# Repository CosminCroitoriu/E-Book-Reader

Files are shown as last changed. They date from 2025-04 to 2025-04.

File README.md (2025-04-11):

Nume: Croitoriu Cosmin-Mircea  
Grupă: 332CB

# TSC Project - OpenBook E-Book Reader
Overview
-
This diagram illustrates the hardware architecture of the OpenBook E-Reader, an ESP32-based electronic paper reading device. The system is built around the ESP32-C6-WROOM-1 microcontroller, which interfaces with a 7.5-inch e-Paper display, environmental sensors, and user input buttons.  

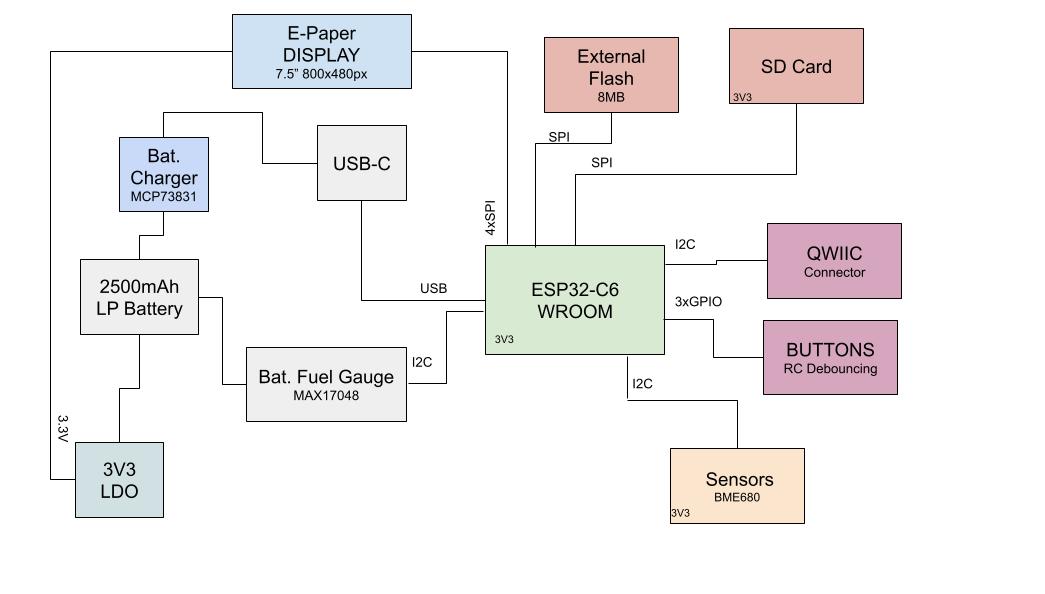
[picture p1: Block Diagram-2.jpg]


***Key Components:*** 

* Core Processing: ESP32-C6 microcontroller with integrated Wi-Fi 6 and BLE 5
* Display: 800×480 resolution e-Paper display connected via SPI
* Sensors: BME688 for temperature, humidity, pressure, and air quality monitoring via I2C
* Power: 2500mAh LiPo battery with fuel gauge and USB-C charging
* Storage: SD card interface for e-book storage via SPI
* Timekeeping: DS3231 RTC with backup power
* User Interface: Buttons via 3xGPIO
* Expansion: QWIIC/Stemma connector for additional peripherals

The firmware is built on FreeRTOS and includes specialized modules for display management, sensor monitoring, battery management, user interface, and e-book rendering. This modular architecture ensures flexible development, easy maintenance, and power-efficient operation—essential for an e-reader device with long battery life requirements.

Power Consumption
-

* In active reading mode (display updated occasionally): ~15-30mA
* In display update mode: ~50-100mA temporarily
* In Wi-Fi active mode: ~120-180mA
* In sleep mode: ~1-5mA
* In deep sleep mode: <50µA

With a 2500mAh battery, the device can operate approximately:

* 100-150 hours in active reading mode (without Wi-Fi)
* 15-20 hours with Wi-Fi constantly active
* Up to 1500 hours (2 months) in deep sleep mode

ESP32-C6 Pin Assignments
-
| Connection Name | GPIO / Pin Name  | Function  |
|---|---|---|
| **3V3** | IO 8 | 3.3V Power line |
| **EN (Reset)**  | EN | Reset Button | 
| **USB_D-** | IO12 | USB Data negative, communication  | 
| **USB_D+** | IO13 | USB Data positive, communication  |
| **Buton Boot**  | IO9 | Bootbutton  | 
| **Buton Change**| IO15 | User input for state changing  |
| **TX (UART)** | TXD0 / GPIO16 | Serial Transmitter (UART) for communication  |
| **RX (UART)** | RXD0 / GPIO17 | Serial Receiver (UART) for communication  |
| **SCK (SPI)** | IO6 | SPI Clock for clock synchronization |
| **MOSI (SPI)**  | IO7 | Transmitter between MC and the Flash, SD Card and display |
| **MISO (SPI)**  | IO2 | Receiver between MC and the Flash, SD Card and display |
| **FLASH_CS** | IO11 | Flash Chip Select |
| **EPD_CS** | IO10 | Display Chip select |
| **EPD_DC** | IO5 | Display Command |
| **EPD_RST** | IO23 | Display Reset |
| **EPD_BUSY** | IO3 | Busy Display Signal |
| **SDA (I2C)** | IO21 | Bidirectional Communication RTC, BME688, Battery Gauge |
| **SCL (I2C)** | IO22 | I2C synchronization |
| **SS_SD** | IO4 | SD Card Chip Select |
| **I2C_PW** | IO19 | Power Control on I2C |
| **EPD_3V3_C** | IO20 | 3.3V Power Line for the Display |
| **32KHZ** | IO1 | 32kHz Signal Input |
| **INT_RTC** | IO0 | RTC DS3231 Interrupt |
| **RTC_RST** | IO18 | External Reset RTC | 

Bill of Materials
-

| Component | Value | Assigned Part | Where to buy | Datasheet |
| --- | --- | --- | --- | ----- |
| Resistor | 15	$\Omega$ | R_CAPACITOR | [Buy](https://ro.mouser.com/ProductDetail/YAGEO/RT0402FRE0715RL?qs=BXCcY9r%252B08DFFpLSkPOIqQ%3D%3D) | [Datasheet](https://ro.mouser.com/datasheet/2/447/PYu_RT_1_to_0_01_RoHS_L_15-3461507.pdf) |
| Resistor | 200 $\Omega$ | R1_BAT | [Buy](https://ro.mouser.com/ProductDetail/Vishay-Beyschlag/MCS0402MD2000BE100?qs=3SvaY9RawMJNVte4F12%252BZQ%3D%3D) | [Datasheet](https://www.vishay.com/doc?28952) |
| Resistor | 100k $\Omega$ | R_PWRUSB | [Buy](https://ro.mouser.com/ProductDetail/Vishay-Beyschlag/MCT0603PD1003DP500?qs=5aG0NVq1C4wWAn8Ei3OpZA%3D%3D) | [Datasheet](https://www.vishay.com/doc?28916) |
| Resistor | 10k $\Omega$ | R1, R1_PINH1, R1_PINH2, R2-PINH1, R2_PINH2, R4, R5, R6, R7, R8, R9, R10, R_BOOT, R_CHANGE, R_CL1, R_RESET | [Buy](https://ro.mouser.com/ProductDetail/Vishay-Beyschlag/MCS0402MD1002BE000?qs=17u8i%2FzlE8%2F9BrAaXkMk1w%3D%3D) | [Datasheet](https://www.vishay.com/doc?28952) |
| Resistor | 0.47 $\Omega$ | R3 | [Buy](https://ro.mouser.com/ProductDetail/SEI-Stackpole/CSR0402JKR470?qs=IPgv5n7u5QawIB6nBEt8wA%3D%3D) | [Datasheet](https://ro.mouser.com/datasheet/2/385/SEI_CSR_CSRN-3077593.pdf) |
| Resistor |  2k $\Omega$ | R2_BAT |[Buy](https://ro.mouser.com/ProductDetail/Vishay-Beyschlag/MCS04020C2001FE000?qs=wTZ%2FFzl837YG0wIkZJJOwQ%3D%3D) | [Datasheet](https://www.vishay.com/doc?28705) |
| Resistor | 2.2 $\Omega$ | R2 | [Buy](https://ro.mouser.com/ProductDetail/SEI-Stackpole/RMCF0402FT2R20?qs=IPgv5n7u5QbBgyl0jwhwsA%3D%3D) | [Datasheet](https://ro.mouser.com/datasheet/2/385/SEI_RMCF_RMCP-3077565.pdf) |
| Resistor | 5k1 $\Omega$ | R1_USB, R2_USB | [Buy](https://www.venkel.com/part/TFCR0603-16W-K-5690FT) | [Datasheet](https://data.venkel.com/documents/tfcr-series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.) |
| Capacitor | 10uF | C6 | [Buy](https://ro.mouser.com/ProductDetail/Samsung-Electro-Mechanics/CL10A106KQ8NNNL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) | [Datasheet](https://ro.mouser.com/datasheet/2/585/MLCC-1837944.pdf) |
| Capacitor | 1uF/50V | EPD_C3 | [Buy](https://ro.mouser.com/ProductDetail/KYOCERA-AVX/06035D105MAT2A?qs=k4kUdCzLgS5%252BURKe1SOIeQ%3D%3D) | [Datasheet](https://ro.mouser.com/datasheet/2/40/cx5r_KGM-3223198.pdf) |
| Capacitor | 4.7uF | C1_BAT, C1_BAT1, C2_BAT, C2_BAT1, C4_USB | [Buy](https://ro.mouser.com/ProductDetail/KYOCERA-AVX/0402ZD475MAT2A?qs=NBFAU1oqP4W4U2PCPHI0sg%3D%3D) | [Datasheet](https://ro.mouser.com/datasheet/2/40/cx5r_KGM-3223198.pdf) |
| Capacitor | 100nF | C1, C2, C3_USB, C5, C7, C8, C9, C_DELAY | [Buy](https://ro.mouser.com/ProductDetail/KYOCERA-AVX/06033G104ZAT2A?qs=NXubJDmysXJMPmHfVo6Z%252BA%3D%3D) | [Datasheet](https://ro.mouser.com/datasheet/2/40/KGM_Y5V-3223189.pdf) |
| PFMF.050.1 | - | PFMF.050.1 | [Buy](https://ro.mouser.com/ProductDetail/Schurter/PFMF.050.2?qs=1auRipcfynCums5v1iucSA%3D%3D) |  [Datasheet](https://ro.mouser.com/datasheet/2/358/typ_PFMF-1275918.pdf) |
| USB4110-GF-A | - | J2 | [Buy](https://ro.mouser.com/ProductDetail/GCT/USB4110-GF-A?qs=KUoIvG%2F9IlYiZvIXQjyJeA%3D%3D) | [Datasheet](https://ro.mouser.com/datasheet/2/837/GCT_USB4110_Product_Drawing___20k_cycles-3455479.pdf) |
| USBLC6-2SC6Y | - | D1 | [Buy](https://ro.mouser.com/ProductDetail/STMicroelectronics/USBLC6-2SC6Y?qs=gNDSiZmRJS%2FOgDexvXkdow%3D%3D) | [Datasheet](https://ro.mouser.com/datasheet/2/389/usblc6_2sc6y-1852505.pdf) |
| SD0805S020S1R0 | - | D2, D7| [Buy](https://ro.mouser.com/ProductDetail/KYOCERA-AVX/SD0805S020S1R0?qs=jCA%252BPfw4LHbpkAoSnwrdjw%3D%3D) | [Datasheet](https://ro.mouser.com/datasheet/2/40/schottky-3165252.pdf) |
| DMG2305UX-7 | - | Q1, Q2 | [Buy](https://ro.mouser.com/ProductDetail/Diodes-Incorporated/DMG2305UX-7?qs=L1DZKBg7t5F%2FNBHrjfxC%252Bg%3D%3D) | [Datasheet](https://www.diodes.com/assets/Datasheets/DMG2305UX.pdf) |
| XC6220A331MR-G | - | U5 | [Buy](https://ro.mouser.com/ProductDetail/Torex-Semiconductor/XC6220A331MR-G?qs=AsjdqWjXhJ8ZSWznL1J0gg%3D%3D) | [Datasheet](https://ro.mouser.com/datasheet/2/760/xc6220-3371556.pdf) |
| Capacitor | 100 uF TANT | C_TANT | [Buy](https://ro.mouser.com/ProductDetail/KYOCERA-AVX/TAJW107M010RNJ?qs=Wtp%252Bf%2FAeVqIH8v1VxV%252B1Rg%3D%3D) | [Datasheet](https://ro.mouser.com/datasheet/2/40/TAJ-3165264.pdf) |
| 112A-TAAR-R03_ATTEND | - | J4 | [Buy](https://www.digikey.ro/en/products/detail/attend-technology/112A-TAAR-R03/17633923) | [Datasheet](https://www.attend.com.tw/data/download/file/112A-TAAR-R03_Spec.pdf)
| ESP32-C6-WROOM-1-N8 | - | U1 | [Buy](https://ro.mouser.com/ProductDetail/Espressif-Systems/ESP32-C6-WROOM-1-N8?qs=8Wlm6%252BaMh8ST02Gmwp74cw%3D%3D) | [Datasheet](https://ro.mouser.com/datasheet/2/891/Espressif_ESP32_C6_WROOM_1__Datasheet_V0_1_PRELIMI-3239987.pdf) |
| MCP73831 | - | U7 | [Buy](https://ro.mouser.com/ProductDetail/Microchip-Technology/MCP73831T-2ACI-OT?qs=yUQqVecv4qvbBQBGbHx0Mw%3D%3D) | [Datasheet](https://ro.mouser.com/datasheet/2/268/MCP73831_Family_Data_Sheet_DS20001984H-3441711.pdf) |
| CHG_LED | - | CHG_LED | [Buy](https://store.comet.srl.ro/Catalogue/Product/40478/) | [Datasheet](https://www.snapeda.com/parts/KP-1608SURCK/Kingbright/datasheet/) |
| SI1308EDL-T1-GE3 | - | Q3 | [Buy](https://ro.mouser.com/ProductDetail/Vishay-Semiconductors/SI1308EDL-T1-GE3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) | [Datasheet](https://www.vishay.com/doc?63399) |
| MBR0530 | - | D3, D4, D5 | [Buy](https://ro.mouser.com/ProductDetail/Micro-Commercial-Components-MCC/MBR0530-T?qs=9VyI4qLX4NTSXkb9ynzJnA%3D%3D) | [Datasheet](https://ro.mouser.com/datasheet/2/258/mcc_mbr0520~mbr0560sod123-1179695.pdf) |
| Power Inductor | 68uH | L1 | [Buy](https://ro.mouser.com/ProductDetail/Wurth-Elektronik/744043680?qs=PGXP4M47uW6VkZq%252BkzjrHA%3D%3D) | [Datasheet](https://www.we-online.com/components/products/datasheet/744043680.pdf) |
| FH34SRJ-24S-0.5SH | - | J1 | [Buy](https://ro.mouser.com/ProductDetail/Hirose-Connector/FH34SRJ-24S-0.5SH99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) | [Datasheet](https://ro.mouser.com/datasheet/2/185/FH34SRJ_24S_0_5SH_99__CL0580_1255_6_99_2DDrawing_0-1615044.pdf) |
| BME688 Sensor | - | U8 | [Buy](https://ro.mouser.com/ProductDetail/Bosch-Sensortec/BME688?qs=IS%252B4QmGtzzqQoVDscqwx3A%3D%3D) | [Datasheet](https://ro.mouser.com/datasheet/2/783/bst_bme688_fl000-2307034.pdf) |
| BD5229G-TR | - | U6 |[Buy](https://ro.mouser.com/ProductDetail/ROHM-Semiconductor/BD5229G-TR?qs=4kLU8WoGk0vvnhrrYwdszw%3D%3D) | [Datasheet](https://fscdn.rohm.com/en/products/databook/datasheet/ic/power/voltage_detector/bd52xxg-e.pdf) |
| PTS841 Button | - | BOOT_BUTTON, CHANGE_BUTTON, RESET_BUTTON | [Buy](https://ro.mouser.com/ProductDetail/CK/PTS841-ESD-GKP-SMTR-LFS?qs=d0WKAl%252BL4KbeUlwuiSQZWA%3D%3D) | [Datasheet](https://www.ckswitches.com/media/2805/pts841.pdf) |
| MAX17048G+T10 | - | U2 | [Buy](https://ro.mouser.com/ProductDetail/Analog-Devices-Maxim-Integrated/MAX17048G%2bT10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) | [Datasheet](https://ro.mouser.com/datasheet/2/609/MAX17048_MAX17049-3469099.pdf) |
| W25Q512JVEIQ | - | U4 | [Buy](https://ro.mouser.com/ProductDetail/Winbond/W25Q512JVEIQ?qs=l7cgNqFNU1jw6svr3at6tA%3D%3D) | [Datasheet](https://ro.mouser.com/datasheet/2/949/Winbond_W25Q512JV_Datasheet-3240039.pdf) |
| PGB1010603MR | - | D6, D8, D9, D10, D11, D12 | [Buy](https://ro.mouser.com/ProductDetail/Littelfuse/PGB1010603MRHF?qs=KvZd0dN2Zg%2FuIq6icj%252BGKA%3D%3D) | [Datasheet](https://www.littelfuse.com/media?itemid=8a337998-d54d-466b-be4e-dc5bcd1f9321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) |
| QWIIC_RIGHT_ANGLE | - | J3 | [Buy](https://ro.mouser.com/ProductDetail/GCT/USB4110-GF-A?qs=KUoIvG%2F9IlYiZvIXQjyJeA%3D%3D) | [Datasheet](https://ro.mouser.com/datasheet/2/837/GCT_USB4110_Product_Drawing___20k_cycles-3455479.pdf) |
| DS3231SN | - | U3 | [Buy](https://ro.mouser.com/ProductDetail/Analog-Devices-Maxim-Integrated/DS3231SN?qs=ffX8NcjNb2RmKAb9wAk9Ug%3D%3D) | [Datasheet](https://ro.mouser.com/datasheet/2/609/DS3231-3421123.pdf) |
| CPH3225A | - | C_SUPERCAP | [Buy](https://ro.mouser.com/ProductDetail/Seiko-Semiconductors/CPH3225A?qs=3etwrb1wR%252BhUOph6lAO7eg%3D%3D) | [Datasheet](https://ro.mouser.com/datasheet/2/360/Seiko_Instruments_MicroBattery_E_20230330_2024Jan_-3561061.pdf) |

Design Considerations
-

* The modular design allows for individual component updates and easy problem diagnosis
* Using a single LDO regulator to generate 3.3V for the entire board simplifies the power design
* Battery charging is done through the USB-C port, ensuring wide compatibility
* The environmental sensors allow for monitoring the conditions in which the device is used and can be used to alert the user about unfavorable conditions
* Used a predefined 3D model for the screen. Source: https://grabcad.com/library/7-5in-e-ink-display-assortment-1

PCB Observations
-

* PCB Dieletctric layer has been reduced from 1.6mm to 1mm to fit in the case.
* Via Stitching has been applied around the MC, so the impedance of the ground plane is lowered.

Errors and Warnings
- 
* The Board Outline Clearence errors were all approved, as every component was matching the placement in the given document.
* Unconnected Lines warnings are a bug from Fusion, as everytime I try to remove them, the error reappears. 
* Copper Width errors for the inductor were approved as the model matched the one in the givne scheme.

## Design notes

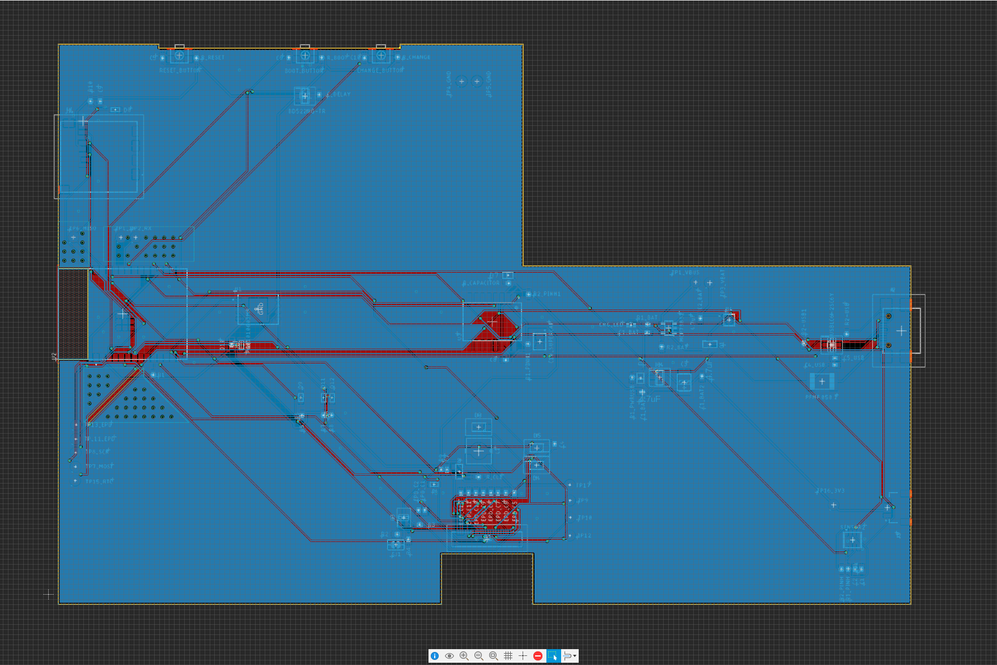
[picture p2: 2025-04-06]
Images/PCB BOTTOM.png

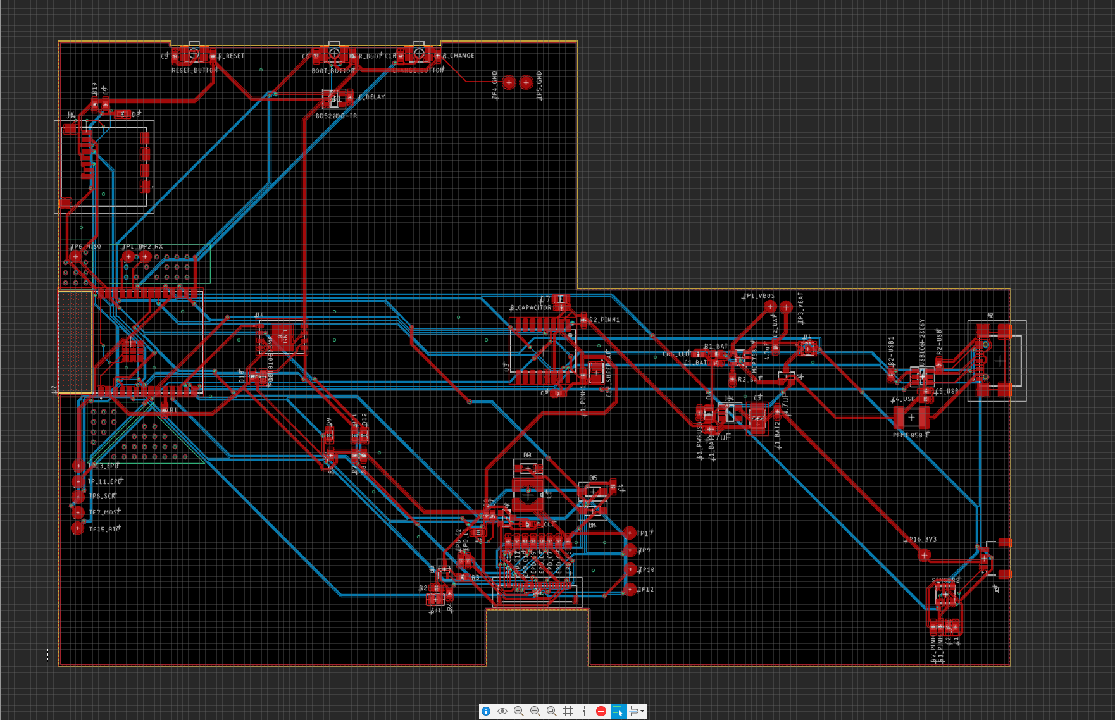
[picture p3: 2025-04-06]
Images/PCB COMPS.png

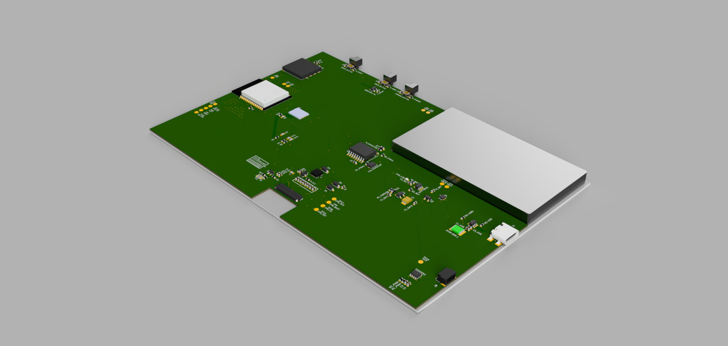
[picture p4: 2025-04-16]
Images/OpenBook_Enclosure Case Fit.jpg

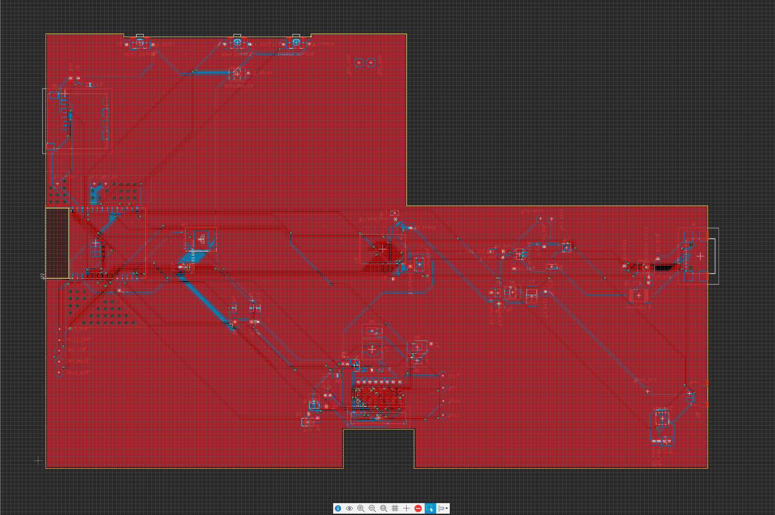
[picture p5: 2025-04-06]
Images/PCB TOP.png

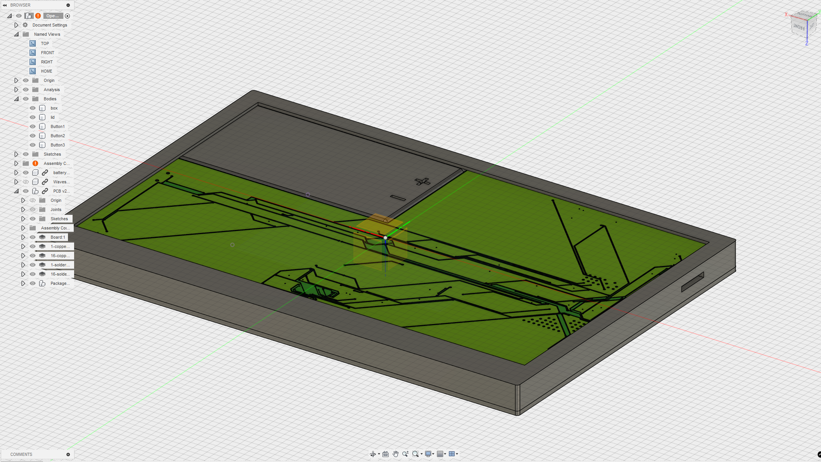
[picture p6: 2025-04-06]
Images/PCB and BATTERY FIT.png

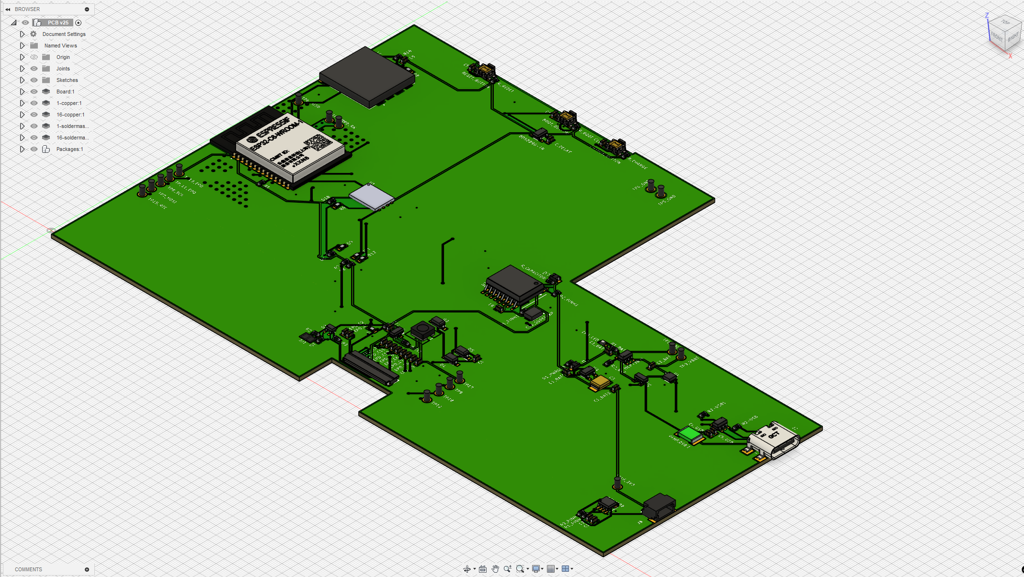
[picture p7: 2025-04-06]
Images/3D PCB.png

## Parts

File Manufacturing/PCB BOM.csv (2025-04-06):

Qty | Value | Device | Package | Parts | Description | ARROW_PART_NUMBER | ARROW_PRICE-STOCK | AVAILABILITY | CENTROID_NOT_SPECIFIED | CHECK_PRICES | COPYRIGHT | DATASHEET | DESCRIPTION | DIGIKEY_DESCRIPTION | DIGIKEY_PART_NUMBER | HEIGHT | LEAD_FREE | MANUFACTURER_NAME | MANUFACTURER_PART_NUMBER | MF | MFR_NAME | MOUSER_PART_NUMBER | MOUSER_PRICE-STOCK | MOUSER_TESTING_PART_NUMBER | MOUSER_TESTING_PRICE-STOCK | MP | MPN | PACKAGE | POPULARITY | PREFIX | PRICE | PROD_ID | PURCHASE-URL | ROHS | SNAPEDA_LINK | SPICEMODEL | SPICEPREFIX | TEMPERATURE_RANGE_HIGH | TEMPERATURE_RANGE_LOW | TP_SIGNAL_NAME | VALUE
1 |  | ADAFRUIT_LEDCHIP-LED0603 | ADAFRUIT_CHIP-LED0603 | CHG_LED | LED
1 |  | SJ | SJ | SJ1 | SMD solder JUMPER |  |  |  |  |  |  |  |  |  |  |  |  |  |  |  |  |  |  |  |  |  |  |  | 3
1 | 0.47 | ESP32_WROVER_EAGLE-LTSPICE_RR0402 | ESP32_WROVER_EAGLE-LTSPICE_R0402 | R3 | RESISTOR, European symbol |  |  |  |  |  |  |  |  |  |  |  |  |  |  |  |  |  |  |  |  |  |  |  |  |  |  |  |  |  |  | NONE | R
1 | 01.uF/50V | EAGLE-LTSPICE_CC0402 | EAGLE-LTSPICE_C0402 | EPD_C5 | CAPACITOR, European symbol |  |  |  |  |  |  |  |  |  |  |  |  |  |  |  |  |  |  |  |  |  |  |  |  |  |  |  |  |  |  | NONE | C
1 | 100K | ESP32_WROVER_EAGLE-LTSPICE_RR0402 | ESP32_WROVER_EAGLE-LTSPICE_R0402 | R1_PWRUSB | RESISTOR, European symbol |  |  |  |  |  |  |  |  |  |  |  |  |  |  |  |  |  |  |  |  |  |  |  |  |  |  |  |  |  |  | NONE | R
8 | 100nF | EAGLE-LTSPICE_CC0402 | EAGLE-LTSPICE_C0402 | C1, C2, C4_USB, C6, C8, C9, C10, C_DELAY | CAPACITOR, European symbol |  |  |  |  |  |  |  |  |  |  |  |  |  |  |  |  |  |  |  |  |  |  |  |  |  |  |  |  |  |  | NONE | C
1 | 100uF TANT | RCL_CPOL-EUCT3528 | RCL_CT3528 | C3 | POLARIZED CAPACITOR, European symbol |  |  |  |  |  |  |  |  |  |  |  |  |  |  |  |  |  |  |  |  |  |  |  | 0 |  |  |  |  |  |  |  | C
11 | 10K | ESP32_WROVER_EAGLE-LTSPICE_RR0402 | ESP32_WROVER_EAGLE-LTSPICE_R0402 | R1_PINH1, R2_PINH1, R5, R6, R7, R8, R9, R10, R_BOOT, R_CHANGE, R_RESET | RESISTOR, European symbol |  |  |  |  |  |  |  |  |  |  |  |  |  |  |  |  |  |  |  |  |  |  |  |  |  |  |  |  |  |  | NONE | R
5 | 10k | ESP32_WROVER_EAGLE-LTSPICE_RR0402 | ESP32_WROVER_EAGLE-LTSPICE_R0402 | R1, R1_PINH, R2_PINH, R4, R_CL1 | RESISTOR, European symbol |  |  |  |  |  |  |  |  |  |  |  |  |  |  |  |  |  |  |  |  |  |  |  |  |  |  |  |  |  |  | NONE | R
1 | 10uF | EAGLE-LTSPICE_CC0402 | EAGLE-LTSPICE_C0402 | C7 | CAPACITOR, European symbol |  |  |  |  |  |  |  |  |  |  |  |  |  |  |  |  |  |  |  |  |  |  |  |  |  |  |  |  |  |  | NONE | C
1 | 112A-TAAR-R03_ATTEND | 112A-TAAR-R03_ATTEND | 112ATAARR03ATTEND | J4 | Micro SD Card Socket, Push-Push Type, Top Mount, SMT, H=1.83mm, 10u |  |  |  |  |  |  |  | Micro SD Card Socket | Push-Push Type | Top Mount | SMT | H=1.83mm | 10u |  |  | 1.9mm |  | ATTEND | 112A-TAAR-R03 ATTEND
1 | 15 | ESP32_WROVER_EAGLE-LTSPICE_RR0402 | ESP32_WROVER_EAGLE-LTSPICE_R0402 | R_CAPACITOR | RESISTOR, European symbol |  |  |  |  |  |  |  |  |  |  |  |  |  |  |  |  |  |  |  |  |  |  |  |  |  |  |  |  |  |  | NONE | R
1 | 1uF | EAGLE-LTSPICE_CC0402 | EAGLE-LTSPICE_C0402 | C5 | CAPACITOR, European symbol |  |  |  |  |  |  |  |  |  |  |  |  |  |  |  |  |  |  |  |  |  |  |  |  |  |  |  |  |  |  | NONE | C
9 | 1uF/50V | EAGLE-LTSPICE_CC0402 | EAGLE-LTSPICE_C0402 | EPD_C1, EPD_C2, EPD_C6, EPD_C7, EPD_C8, EPD_C9, EPD_C10, EPD_C11, EPD_C12 | CAPACITOR, European symbol |  |  |  |  |  |  |  |  |  |  |  |  |  |  |  |  |  |  |  |  |  |  |  |  |  |  |  |  |  |  | NONE | C
1 | 2.2 | ESP32_WROVER_EAGLE-LTSPICE_RR0402 | ESP32_WROVER_EAGLE-LTSPICE_R0402 | R2 | RESISTOR, European symbol |  |  |  |  |  |  |  |  |  |  |  |  |  |  |  |  |  |  |  |  |  |  |  |  |  |  |  |  |  |  | NONE | R
1 | 200 | ESP32_WROVER_EAGLE-LTSPICE_RR0402 | ESP32_WROVER_EAGLE-LTSPICE_R0402 | R1_BAT | RESISTOR, European symbol |  |  |  |  |  |  |  |  |  |  |  |  |  |  |  |  |  |  |  |  |  |  |  |  |  |  |  |  |  |  | NONE | R
2 | 20V/4.2A/52mO/1.4W | ESP32_WROVER_SPARKFUN-DISCRETESEMI_MOSFET_PCH-DMG2305UX-7 | ESP32_WROVER_SPARKFUN-DISCRETESEMI_SOT23-3 | Q1, Q2 | P-channel MOSFETs |  |  |  |  |  |  |  |  |  |  |  |  |  |  |  |  |  |  |  |  |  |  |  |  |  |  | TRAN-14388 |  |  |  |  |  |  |  |  | 20V/4.2A/52mO/1.4W
1 | 2K | ESP32_WROVER_EAGLE-LTSPICE_RR0402 | ESP32_WROVER_EAGLE-LTSPICE_R0402 | R2_BAT | RESISTOR, European symbol |  |  |  |  |  |  |  |  |  |  |  |  |  |  |  |  |  |  |  |  |  |  |  |  |  |  |  |  |  |  | NONE | R
3 | 4.7uF | EAGLE-LTSPICE_CC0402 | EAGLE-LTSPICE_C0402 | C1_BAT, C2_BAT, C5_USB | CAPACITOR, European symbol |  |  |  |  |  |  |  |  |  |  |  |  |  |  |  |  |  |  |  |  |  |  |  |  |  |  |  |  |  |  | NONE | C
2 | 4.7uF | ESP32_WROVER_EAGLE-LTSPICE_CC0402 | EAGLE-LTSPICE_C0402 | C1_BAT1, C1_BAT2 | CAPACITOR, European symbol |  |  |  |  |  |  |  |  |  |  |  |  |  |  |  |  |  |  |  |  |  |  |  |  |  |  |  |  |  |  | NONE | C
1 | 4.7uF/25V | EAGLE-LTSPICE_CC0402 | EAGLE-LTSPICE_C0402 | C4 | CAPACITOR, European symbol |  |  |  |  |  |  |  |  |  |  |  |  |  |  |  |  |  |  |  |  |  |  |  |  |  |  |  |  |  |  | NONE | C
2 | 5k1 | ESP32_WROVER_EAGLE-LTSPICE_RR0402 | ESP32_WROVER_EAGLE-LTSPICE_R0402 | R2-USB, R2-USB1 | RESISTOR, European symbol |  |  |  |  |  |  |  |  |  |  |  |  |  |  |  |  |  |  |  |  |  |  |  |  |  |  |  |  |  |  | NONE | R
1 | 68uH | 744043680IND_4828-WE-TPC_WRE | IND_4828-WE-TPC_WRE | L1 |  |  |  |  |  |  | Copyright (C) 2024 Ultra Librarian. All rights reserved. |  |  |  |  |  |  |  | 744043680 |  | Wurth Electronics
1 | BD5229G-TR | BD5229G-TR | SOT95P280X125-5N | IC1 | Voltage Detector with Adjustable Delay Time: CMOS processes are utilized to develop high precision, low current consumption CMOS reset ICs that allow arbitrary setting of the delay time. The extensive lineup includes both Nch Open Drain and CMOS output types in a wide range of detection voltages (from 2.3V to 6.0V, in 0.1V steps), enabling selection of the ideal solution based on customer requirements. In addition, the entire series is of course both lead-free and RoHS-compliant. |  |  |  |  |  |  |  | Voltage Detector with Adjustable Delay Time: CMOS processes are utilized to develop high precision | low current consumption CMOS reset ICs that allow arbitrary setting of the delay time. The extensive lineup includes both Nch Open Drain and CMOS output types in a wide range of detection voltages (from 2.3V to 6.0V | in 0.1V steps) | enabling selection of the ideal solution based on customer requirements. In addition | the entire series is of course both lead-free and RoHS-compliant. |  |  | 1.25mm |  | ROHM Semiconductor | BD5229G-TR |  |  | 755-BD5229G-TR | https://www.mouser.co.uk/ProductDetail/ROHM-Semiconductor/BD5229G-TR?qs=4kLU8WoGk0vvnhrrYwdszw%3D%3D
3 | BUTTON_CUSYOMV1 | BUTTON_CUSYOMV1 | MYBUTTON | BOOT_BUTTON, CHANGE_BUTTON, RESET_BUTTON
1 | CPH3225A | CPH3225A | CAPCP3225X100N | C10_SUPERCAP | Cap 0.011F 3.3V 1210 Flat Check availability |  |  | Not in stock |  | https://www.snapeda.com/parts/CPH3225A/Seiko+Instruments/view-part/?ref=eda |  |  | 11 mF (EDLC) Supercapacitor 3.3 V 1210 (3225 Metric) - - |  |  |  |  |  |  | Seiko Instruments |  |  |  |  |  | CPH3225A |  | 1210 Seiko |  |  | None |  | https://www.snapeda.com/api/url_track_click_mouser/?unipart_id=562593&manufacturer=Seiko Instruments&part_name=CPH3225A&search_term=None |  | https://www.snapeda.com/parts/CPH3225A/Seiko+Instruments/view-part/?ref=snap
1 | DS3231SN# | DS3231SN# | SOIC127P1032X265-16N | U3 | Real Time Clock Serial 16-Pin SOIC W T/R Check availability |  |  | In Stock |  | https://www.snapeda.com/parts/DS3231SN%23/Analog+Devices/view-part/?ref=eda |  |  | Extremely Accurate I²C-Integrated RTC/TCXO/Crystal |  |  |  |  |  |  | Analog Devices |  |  |  |  |  | DS3231SN# |  | SOIC-16 Maxim |  |  | None |  | https://www.snapeda.com/api/url_track_click_mouser/?unipart_id=99048&manufacturer=Analog Devices&part_name=DS3231SN#&search_term=None |  | https://www.snapeda.com/parts/DS3231SN%23/Analog+Devices/view-part/?ref=snap
1 | ESP32-C6-WROOM-1-N8 | ESP32-C6-WROOM-1-N8 | XCVR_ESP32-C6-WROOM-1-N8 | U2 | Check availability |  |  | In Stock |  | https://www.snapeda.com/parts/ESP32-C6-WROOM-1-N8/Espressif+Systems/view-part/?ref=eda |  |  | Multiprotocol Modules ESP32-C6 module | Wi-Fi 6 in 2.4 GHz band | Bluetooth 5 | Zigbee 3.0 and Thread. ESP34-WROOM Compatible - ENGINEERING SAMPLE |  |  |  |  |  |  | Espressif Systems |  |  |  |  |  | ESP32-C6-WROOM-1-N8 |  | None |  |  | None |  |  |  | https://www.snapeda.com/parts/ESP32-C6-WROOM-1-N8/Espressif+Systems/view-part/?ref=snap
1 | ESP32C6_VARISTORCN1812 | ESP32C6_VARISTORCN1812 | ESP32C6_VARISTOR_CT/CN1812 | PFMF.050.1 | VARISTOR |  |  |  |  |  |  |  |  |  |  |  |  |  |  |  |  |  |  |  |  |  |  |  | 0
2 | ESP32_WROVER_AVX---SD0805S020S1R0_AVX_SD0805S020S1R0_0_0AVX_SD0805S020S1R0_0_0 | ESP32_WROVER_AVX---SD0805S020S1R0_AVX_SD0805S020S1R0_0_0AVX_SD0805S020S1R0_0_0 | ESP32_WROVER_AVX---SD0805S020S1R0_AVX_SD0805S020S1R0_0 | D2, D7 | Schottky Barrier Rectifier Diode |  |  |  | No |  |  | http://datasheets.avx.com/schottky.pdf |  | DIODE SCHOTTKY 20V 1A 0805 | 478-7800-1-ND |  | yes |  |  | AVX |  | 581-SD0805S020S1R0 |  |  |  |  |  | 0805 (2012 metric) |  | D |  |  |  | yes |  |  |  | +125°C | -55°C
1 | ESP32_WROVER_BME680_BME680 | ESP32_WROVER_BME680_BME680 | ESP32_WROVER_BME680_PSON80P300X300X100-8N | SENSOR2 | Integrated Environmental Unit |  |  | Unavailable |  |  |  |  | Integrated Environmental Unit |  |  |  |  |  |  | Bosch Sensortec |  |  |  |  |  | BME680 |  | LGA-8 Bosch Tools |  |  | None
1 | ESP32_WROVER_SPARKFUN-IC-POWER_MCP73831 | ESP32_WROVER_SPARKFUN-IC-POWER_MCP73831 | ESP32_WROVER_SPARKFUN-IC-POWER_SOT23-5 | MCP73831 | MCP73831T Li-Ion, Li-Pol Controller |  |  |  |  |  |  |  |  |  |  |  |  |  |  |  |  |  |  |  |  |  |  |  |  |  |  | IC-09995
1 | FH34SRJ-24S-0.5SH_99_ | FH34SRJ-24S-0.5SH_99_ | FH34SRJ24S05SH99 | J1 | (0.50mm) Surface Mount, Right Angle |  |  |  |  |  |  |  | 24 Position FFC | FPC Connector Contacts | (0.50mm) Surface Mount | Right Angle |  |  | 1.1mm |  | Hirose | FH34SRJ-24S-0.5SH(99) |  |  | 798-FH34SRJ24S05SH99 | https://www.mouser.co.uk/ProductDetail/Hirose-Connector/FH34SRJ-24S-0.5SH99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
1 | MAX17048G+T10 | MAX17048G+T10 | SON50P200X200X80-9N | U4 | Check availability |  |  | In Stock |  | https://www.snapeda.com/parts/MAX17048G+T10/Analog+Devices/view-part/?ref=eda |  |  | 3µA 1-Cell/2-Cell Fuel Gauge with ModelGauge |  |  |  |  |  |  | Analog Devices |  |  |  |  |  | MAX17048G+T10 |  | TDFN-8 Maxim |  |  | None |  | https://www.snapeda.com/api/url_track_click_mouser/?unipart_id=329239&manufacturer=Analog Devices&part_name=MAX17048G+T10&search_term=None |  | https://www.snapeda.com/parts/MAX17048G+T10/Analog+Devices/view-part/?ref=snap
3 | MBR0530 | MBR0530 | SOD3716X135N | D3, D4, D5 | ON SEMICONDUCTOR - MBR0530 - DIODE, SCHOTTKY, 0.5A, 30V, SOD-123 |  |  | In Stock |  | https://www.snapeda.com/parts/MBR0530/Onsemi/view-part/?ref=eda |  |  | Diode Schottky 30 V 500mA Surface Mount SOD-123 |  |  |  |  |  |  | ON Semiconductor |  |  |  |  |  | MBR0530 |  | SOD-123-2 ON Semiconductor |  |  | None |  | https://www.snapeda.com/api/url_track_click_mouser/?unipart_id=179458&manufacturer=ON Semiconductor&part_name=MBR0530&search_term=None |  | https://www.snapeda.com/parts/MBR0530/Onsemi/view-part/?ref=snap
6 | PGB1010603MR | PGB1010603MR | DIOC1608X36N | D6, D8, D9, D10, D11, D12 | Check availability |  |  | In Stock |  | https://www.snapeda.com/parts/PGB1010603MR/Littelfuse/view-part/?ref=eda |  |  | 150V (Typ) Clamp - Ipp Tvs Diode Surface Mount 0603 (1608 Metric) |  |  |  |  |  |  | Littelfuse Inc. |  |  |  |  |  | PGB1010603MR |  | 0603 Littelfuse Inc. |  |  | None |  | https://www.snapeda.com/api/url_track_click_mouser/?unipart_id=5659453&manufacturer=Littelfuse Inc.&part_name=PGB1010603MR&search_term=None |  | https://www.snapeda.com/parts/PGB1010603MR/Littelfuse/view-part/?ref=snap
1 | QWIIC_RIGHT_ANGLE | QWIIC_CONNECTORJS-1MM | JST04_1MM_RA | J3 | SparkFun I2C Standard Qwiic Connector |  |  |  |  |  |  |  |  |  |  |  |  |  |  |  |  |  |  |  |  |  |  |  |  |  |  | CONN-13694 |  |  |  |  |  |  |  |  | QWIIC_RIGHT_ANGLE
1 | SAMACSYS_PARTS_USB4110-GF-A | SAMACSYS_PARTS_USB4110-GF-A | SAMACSYS_PARTS_USB4110GFA | J2 | CONN USB 2.0 TYPE-C R/A SMT |  |  |  |  |  |  |  | CONN USB 2.0 TYPE-C R/A SMT |  |  | 3.26mm |  | GCT (GLOBAL CONNECTOR TECHNOLOGY) | USB4110-GF-A |  |  | 640-USB4110-GF-A | https://www.mouser.co.uk/ProductDetail/GCT/USB4110-GF-A?qs=KUoIvG%2F9IlYiZvIXQjyJeA%3D%3D
1 | SI1308EDL-T1-GE3 | SI1308EDL-T1-GE3 | SOT65P210X110-3N | Q3 | MOSFET N-Ch 30V 1.5A TrenchFET SC70 Vishay Si1308EDL-T1-GE3 N-channel MOSFET Transistor, 1.5 A, 30 V, 3-Pin SC-70 |  |  | In Stock |  | https://www.snapeda.com/parts/SI1308EDL-T1-GE3/Vishay+Siliconix/view-part/?ref=eda |  |  | Si1308EDL-T1-GE3 N-channel MOSFET Transistor | 1.5 A | 30 V | 3-Pin SC-70 | Siliconix / Vishay SI1308EDL-T1-GE3 |  |  |  |  |  |  | Vishay Siliconix |  |  |  |  |  | SI1308EDL-T1-GE3 |  | SOT-323 Vishay Semiconductor |  |  | None |  | https://www.snapeda.com/api/url_track_click_mouser/?unipart_id=274603&manufacturer=Vishay Siliconix&part_name=SI1308EDL-T1-GE3&search_term=None |  | https://www.snapeda.com/parts/SI1308EDL-T1-GE3/Vishay+Siliconix/view-part/?ref=snap
17 | TPTP20R | TPTP20R | TP20R | TP1_TX, TP1_VBUS, TP2_RX, TP3_VBAT, TP4_GND, TP5_GND, TP6_MISO, TP7_MOSI, TP8_SCK, TP9, TP10, TP12, TP13_EPD, TP15_RTC, TP16_3V3, TP17, TP_11_EPD | Test pad |  |  |  |  |  |  |  |  |  |  |  |  |  |  |  |  |  |  |  |  |  |  |  | 2
1 | USBLC6-2SC6Y | USBLC6-2SC6Y | SOT95P280X145-6N | D1 | Low Cap. ESD Protection Auto SOT-23-6 STMicroelectronics USBLC6-2SC6Y, Dual Uni-Directional TVS Diode Array, 6-Pin SOT-23 |  |  | In Stock |  | https://www.snapeda.com/parts/USBLC6-2SC6Y/STMicroelectronics/view-part/?ref=eda |  |  | 17V Clamp 5A (8/20µs) Ipp Tvs Diode Surface Mount SOT-23-6 |  |  |  |  |  |  | STMicroelectronics |  |  |  |  |  | USBLC6-2SC6Y |  | SOT-23-6 STMicroelectronics |  |  | None |  |  |  | https://www.snapeda.com/parts/USBLC6-2SC6Y/STMicroelectronics/view-part/?ref=snap
1 | W25Q512JVEIQ | W25Q512JVEIQ | SON127P600X800X80-9N | U1 | Check availability |  |  | In Stock |  | https://www.snapeda.com/parts/W25Q512JVEIQ/Winbond+Electronics/view-part/?ref=eda |  |  | FLASH - NOR Memory IC 512Mb (64M x 8) SPI - Quad I/O 133 MHz 8-WSON (8x6) |  |  |  |  |  |  | Winbond Electronics |  |  |  |  |  | W25Q512JVEIQ |  | Package |  |  | None |  |  |  | https://www.snapeda.com/parts/W25Q512JVEIQ/Winbond+Electronics/view-part/?ref=snap
1 | XC6220A331MR-G | XC6220A331MR-G | SOT95P280X120-5N | IC4 | LDO Voltage Regulators |  |  |  |  |  |  |  | LDO Voltage Regulators |  |  | 1.2mm |  | Torex | XC6220A331MR-G |  |  | 865-XC6220A331MR-G | https://www.mouser.co.uk/ProductDetail/Torex-Semiconductor/XC6220A331MR-G?qs=AsjdqWjXhJ8ZSWznL1J0gg%3D%3D

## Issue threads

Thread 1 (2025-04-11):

[Footprint] SENSOR2 appears elevated above PCB in 3D view

MBuzbuchi, 2025-04-11:
## Descriere:
În vizualizarea 3D a boardului, componenta labeled SENSOR2 apare suspendată deasupra suprafeței PCB-ului.  Cel mai probabil ti-au fost prajiti ochii de la 8 ore petrecute in interfata de la Fusion, astfel modelul 3D are un offset incorect pe axa Z sau nu este corect aliniat cu footprint-ul folosit în schema de pe reprezentarea 2D.

## Checklist:
Conform Chechklist (a.k.a ANPC ul PCB urilor ) problema asta intra in categoria: "3D models obtained (if available) and checked against footprints"

## Sugestie remediere
Deschide vizualizare 3D a PCB
Selecteaza componenta Sensor2
Trage Componenta mai in jos pe axa Z astfel incat sa se alieneze cu pad-ul si pinurile

## Reprezentare vizuala:
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

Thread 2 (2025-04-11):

[Schematics] Schematic lacks functional block labels / titles

MBuzbuchi, 2025-04-11:
## Descriere:

Schematic-ul curent nu contine label-uri/titluri care sa descrie rolul fiecarei grupari de componente (ex: „LDO Regulator”, „Microcontroller”, „Sensor”, „USB Protection” etc.).

Astfel intelegerea rapida a functiilor fiecarui bloc este ingreunata, mai ales pentru alti colaboratori sau in faze ulterioare ale proiectului (revizii, debugging, productie, testare).

## Recomandare:
Adauga un titlu sumar descriptiv al gruparii de componente/compoenentei folosind tabul de document

## Reprezentare vizuala:
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

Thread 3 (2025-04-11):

[Silkscreen] SilkScreen Text missplacement

MBuzbuchi, 2025-04-11:
## Descriere:

Pe layout-ul PCB, anumite etichete de silkscreen (IC1, D1,) sunt plasate pe un layer diferit față de componenta pe care o descriu (ex: silkscreen, componentă pe top), si din moment ce componenta se afla exact deasupra etichetei din silkscreen ajunge sa o acopere astfel ca in reprezentarea 3D nu este deloc vizibila.

O situatie asemnatoare este pentru unele componente care prezinta nume dublate probabil din neatentie (rezistente R5 si R8).

Iar unele Test point uri par sa si intersecteze/suprapuna label urile de text, fapt care poate duce la text ilizibil dupa fabricare, risc de stergere partiala la lipire (afecteaza calitate print) si ambiguitate in identificare Tp-uri

## Checklist:
Conform Checklist ptoblema se incadreaza in "Text not overlapping drills or component pads "

## Sugestii:
Cauta o pozitionare mai spatiata a tp urilor (intr o limita rezonabila) si sa nu si intersecteze air wire urile (eviti numar de vias-uri crescut), muta label urile corespunzatoare silkscreenurilor semnalate in alta pozitie cat mai apropiate de componenta pe care o reprezinta (ex: mai la stanga/ mai jos) iar pentru numele dublate doar da stick la 1 singura.

## Reprezentare vizuala:

## Overshadow:
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

## Repetare label:

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

## Tp too-close:

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

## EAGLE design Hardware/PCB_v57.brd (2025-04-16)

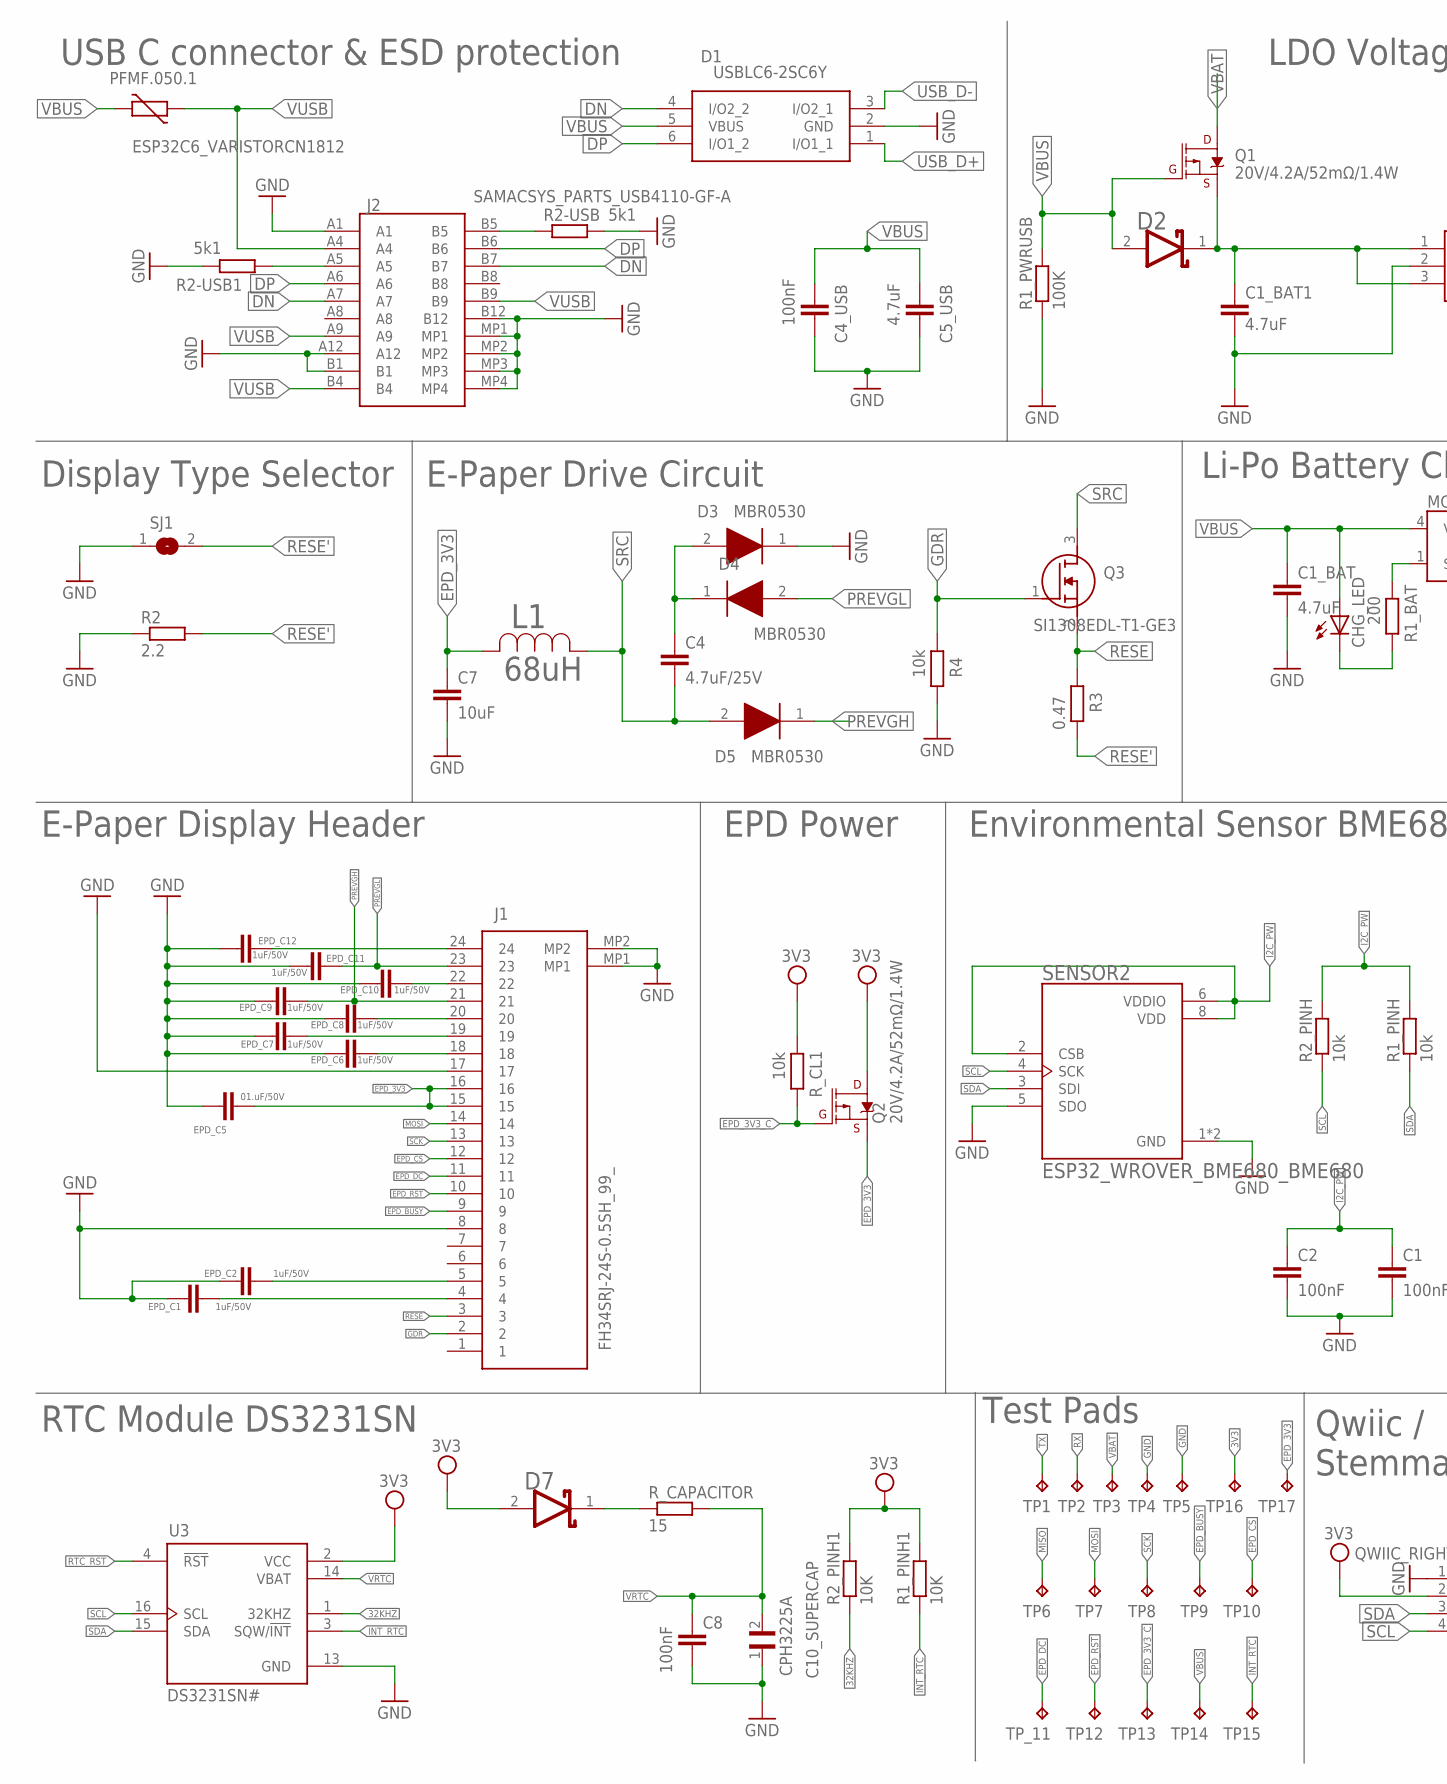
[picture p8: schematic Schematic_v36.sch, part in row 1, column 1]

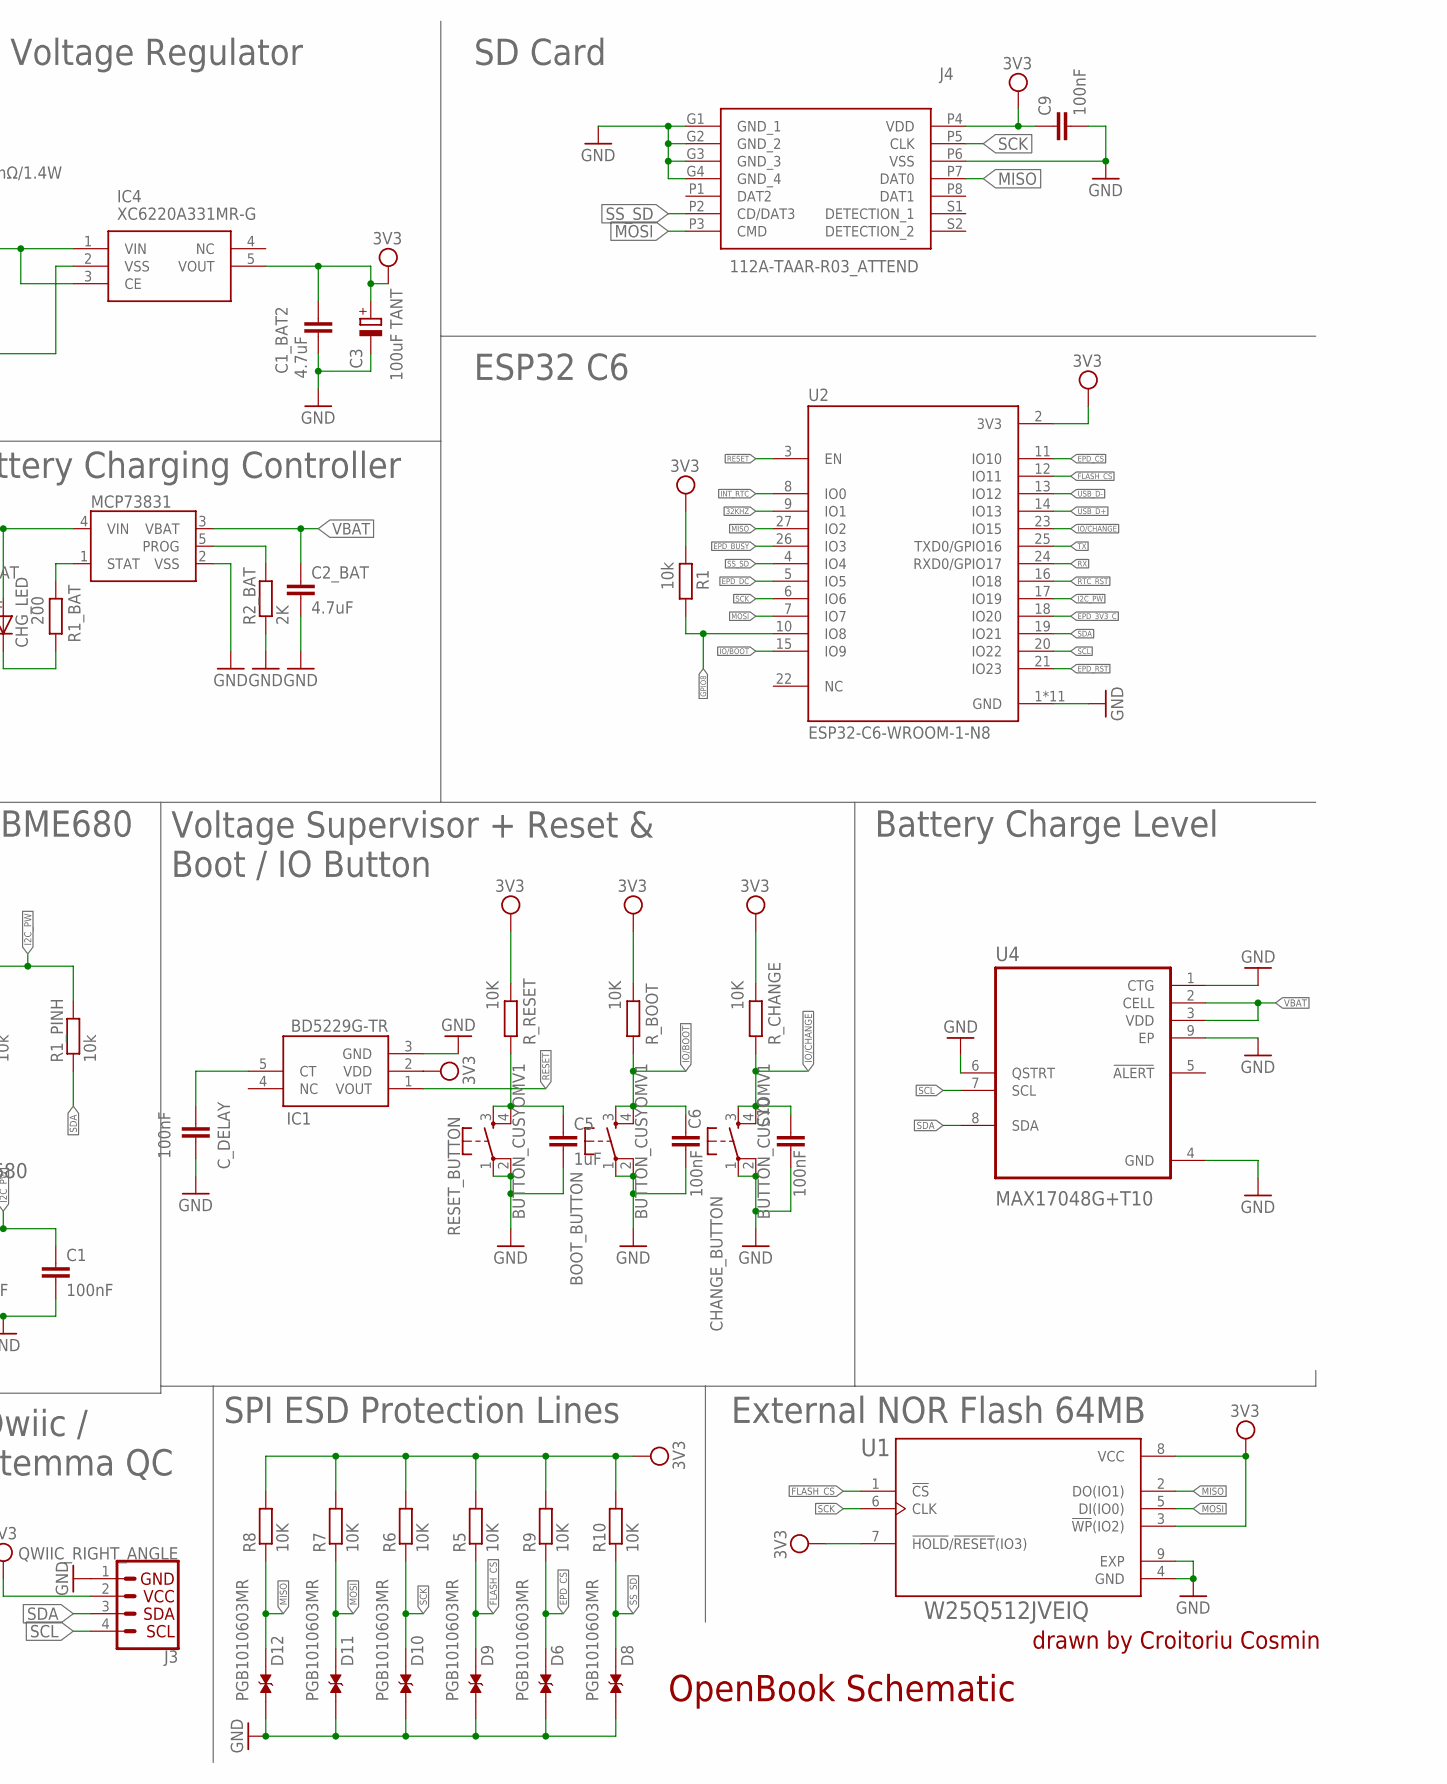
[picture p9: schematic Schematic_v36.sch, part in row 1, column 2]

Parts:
BOOT_BUTTON: BUTTON_CUSYOMV1; MYBUTTON
C1, C2, C4_USB, C6, C8, C9, C10: 100nF; EAGLE-LTSPICE_C0402
C1_BAT, C1_BAT1, C1_BAT2, C2_BAT, C5_USB: 4.7uF; EAGLE-LTSPICE_C0402
C3: 100uF TANT; RCL_CT3528
C4: 4.7uF/25V; EAGLE-LTSPICE_C0402
C5: 1uF; EAGLE-LTSPICE_C0402
C7: 10uF; EAGLE-LTSPICE_C0402
C10_SUPERCAP: CPH3225A; CAPCP3225X100N
CHANGE_BUTTON: BUTTON_CUSYOMV1; MYBUTTON
CHG_LED: ADAFRUIT_LEDCHIP-LED0603; ADAFRUIT_CHIP-LED0603
C_DELAY: 100nF; EAGLE-LTSPICE_C0402
D1: USBLC6-2SC6Y; SOT95P280X145-6N
D2, D7: ESP32_WROVER_AVX---SD0805S020S1R0_AVX_SD0805S020S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; ESP32_WROVER_AVX---SD0805S020S1R0_AVX_SD0805S020S1R0_0
D3, D4, D5: MBR0530; SOD3716X135N
D6, D8, D9, D10, D11, D12: PGB1010603MR; DIOC1608X36N
EPD_C1, EPD_C2, EPD_C6, EPD_C7, EPD_C8, EPD_C9, EPD_C10, EPD_C11, EPD_C12: 1uF/50V; EAGLE-LTSPICE_C0402
EPD_C5: 01.uF/50V; EAGLE-LTSPICE_C0402
IC1: BD5229G-TR; SOT95P280X125-5N
IC4: XC6220A331MR-G; SOT95P280X120-5N
J1: FH34SRJ-24S-0.5SH_99_; FH34SRJ24S05SH99
J2: SAMACSYS_PARTS_USB4110-GF-A; SAMACSYS_PARTS_USB4110GFA
J3: QWIIC_RIGHT_ANGLE; JST04_1MM_RA
J4: 112A-TAAR-R03_ATTEND; 112ATAARR03ATTEND
L1: 68uH; IND_4828-WE-TPC_WRE
MCP73831: ESP32_WROVER_SPARKFUN-IC-POWER_MCP73831; ESP32_WROVER_SPARKFUN-IC-POWER_SOT23-5
PFMF.050.1: ESP32C6_VARISTORCN1812; ESP32C6_VARISTOR_CT/CN1812
Q1, Q2: 20V/4.2A/52mΩ/1.4W; ESP32_WROVER_SPARKFUN-DISCRETESEMI_SOT23-3
Q3: SI1308EDL-T1-GE3; SOT65P210X110-3N
R1, R1_PINH, R2_PINH, R4: 10k; ESP32_WROVER_EAGLE-LTSPICE_R0402
R1_BAT: 200; ESP32_WROVER_EAGLE-LTSPICE_R0402
R1_PINH1, R2_PINH1, R5, R6, R7, R8, R9, R10: 10K; ESP32_WROVER_EAGLE-LTSPICE_R0402
R1_PWRUSB: 100K; ESP32_WROVER_EAGLE-LTSPICE_R0402
R2: 2.2; ESP32_WROVER_EAGLE-LTSPICE_R0402
R2-USB, R2-USB1: 5k1; ESP32_WROVER_EAGLE-LTSPICE_R0402
R2_BAT: 2K; ESP32_WROVER_EAGLE-LTSPICE_R0402
R3: 0.47; ESP32_WROVER_EAGLE-LTSPICE_R0402
RESET_BUTTON: BUTTON_CUSYOMV1; MYBUTTON
R_BOOT: 10K; ESP32_WROVER_EAGLE-LTSPICE_R0402
R_CAPACITOR: 15; ESP32_WROVER_EAGLE-LTSPICE_R0402
R_CHANGE: 10K; ESP32_WROVER_EAGLE-LTSPICE_R0402
R_CL1: 10k; ESP32_WROVER_EAGLE-LTSPICE_R0402
R_RESET: 10K; ESP32_WROVER_EAGLE-LTSPICE_R0402
SENSOR2: ESP32_WROVER_BME680_BME680; ESP32_WROVER_BME680_PSON80P300X300X100-8N
SJ1: SJ
TP1, TP2, TP3, TP4, TP5, TP6, TP7, TP8, TP9, TP10, TP12, TP13, TP14, TP15, TP16, TP17: TPTP20R; TP20R
TP_11: TPTP20R; TP20R
U1: W25Q512JVEIQ; SON127P600X800X80-9N
U2: ESP32-C6-WROOM-1-N8; XCVR_ESP32-C6-WROOM-1-N8
U3: DS3231SN#; SOIC127P1032X265-16N
U4: MAX17048G+T10; SON50P200X200X80-9N

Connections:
3V3: C1_BAT2.2, C3.+, C9.1, D7.2 (ANODE), IC1.2 (VDD), IC4.5 (VOUT), J3.2, J4.P4 (VDD), Q2.3 (D), R1.2, R1_PINH1.2, R2_PINH1.2, R5.2, R6.2, R7.2, R8.2, R9.2, R10.2, R_BOOT.2, R_CHANGE.2, R_CL1.2, R_RESET.2, TP16.TP, U1.3 (!WP!(IO2)), U1.7 (!HOLD!/!RESET!(IO3)), U1.8 (VCC), U2.2 (3V3), U3.2 (VCC)
32KHZ: R2_PINH1.1, U2.9 (IO1), U3.1 (32KHZ)
DN: D1.4 (I/O2_2), J2.A7, J2.B7
DP: D1.6 (I/O1_2), J2.A6, J2.B6
EPD_3V3: C7.1, EPD_C5.2, J1.15, J1.16, L1.2, Q2.2 (S), TP17.TP
EPD_3V3_C: Q2.1 (G), R_CL1.1, TP13.TP, U2.18 (IO20)
EPD_BUSY: J1.9, TP9.TP, U2.26 (IO3)
EPD_CS: D6.2, J1.12, R9.1, TP10.TP, U2.11 (IO10)
EPD_DC: J1.11, TP_11.TP, U2.5 (IO5)
EPD_RST: J1.10, TP12.TP, U2.21 (IO23)
FLASH_CS: D9.2, R5.1, U1.1 (!CS), U2.12 (IO11)
GDR: J1.2, Q3.1 (G), R4.2
GND: BOOT_BUTTON.1, BOOT_BUTTON.2, C1.2, C1_BAT.2, C1_BAT1.1, C1_BAT2.1, C2.2, C2_BAT.2, C3.-, C4_USB.2, C5.2, C5_USB.2, C6.2, C7.2, C8.2, C9.2, C10.2, C10_SUPERCAP.1, CHANGE_BUTTON.1, CHANGE_BUTTON.2, C_DELAY.2, D1.2 (GND), D3.1 (K), D6.1, D8.1, D9.1, D10.1, D11.1, D12.1, EPD_C1.1, EPD_C2.1, EPD_C5.1, EPD_C6.1, EPD_C7.1, EPD_C8.1, EPD_C9.1, EPD_C10.1, EPD_C11.1, EPD_C12.1, IC1.3 (GND), IC4.2 (VSS), J1.8, J1.17, J1.MP1, J1.MP2, J2.A1, J2.A12, J2.B1, J2.B12, J2.MP1, J2.MP2, J2.MP3, J2.MP4, J3.1, J4.G1 (GND_1), J4.G2 (GND_2), J4.G3 (GND_3), J4.G4 (GND_4), J4.P6 (VSS), MCP73831.2 (VSS), R1_PWRUSB.1, R2.1, R2-USB.2, R2-USB1.1, R2_BAT.1, R4.1, RESET_BUTTON.1, RESET_BUTTON.2, SENSOR2.1 (GND), SENSOR2.5 (SDO), SENSOR2.7 (GND), SJ1.1, TP4.TP, TP5.TP, U1.4 (GND), U1.9 (EXP), U2.1 (GND), U2.28 (GND), U2.29_1 (GND), U2.29_2 (GND), U2.29_3 (GND), U2.29_4 (GND), U2.29_5 (GND), U2.29_6 (GND), U2.29_7 (GND), U2.29_8 (GND), U2.29_9 (GND), U3.13 (GND), U4.1 (CTG), U4.4 (GND), U4.6 (QSTRT), U4.9 (EP)
GPIO8: R1.1, U2.10 (IO8)
I2C_PW: C1.1, C2.1, R1_PINH.2, R2_PINH.2, SENSOR2.2 (CSB), SENSOR2.6 (VDDIO), SENSOR2.8 (VDD), U2.17 (IO19)
INT_RTC: R1_PINH1.1, TP15.TP, U2.8 (IO0), U3.3 (SQW/!INT)
IO/BOOT: BOOT_BUTTON.3, BOOT_BUTTON.4, C6.1, R_BOOT.1, U2.15 (IO9)
IO/CHANGE: C10.1, CHANGE_BUTTON.3, CHANGE_BUTTON.4, R_CHANGE.1, U2.23 (IO15)
MISO: D12.2, J4.P7 (DAT0), R8.1, TP6.TP, U1.2 (DO(IO1)), U2.27 (IO2)
MOSI: D11.2, J1.14, J4.P3 (CMD), R7.1, TP7.TP, U1.5 (DI(IO0)), U2.7 (IO7)
unnamed: J2.A5, R2-USB1.2
unnamed: J2.B5, R2-USB.1
unnamed: C1_BAT1.2, D2.1 (CATHODE), IC4.1 (VIN), IC4.3 (CE), Q1.2 (S)
unnamed: CHG_LED.C, R1_BAT.1
unnamed: MCP73831.1 (STAT), R1_BAT.2
unnamed: C4.1, D3.2 (A), D4.1 (K)
unnamed: MCP73831.5 (PROG), R2_BAT.2
unnamed: EPD_C12.2, J1.24
unnamed: C_DELAY.1, IC1.5 (CT)
unnamed: EPD_C10.2, J1.22
unnamed: C5.1, RESET_BUTTON.3, RESET_BUTTON.4, R_RESET.1
unnamed: EPD_C8.2, J1.20
unnamed: EPD_C7.2, J1.19
unnamed: EPD_C6.2, J1.18
unnamed: D7.1 (CATHODE), R_CAPACITOR.1
unnamed: EPD_C2.2, J1.5
unnamed: EPD_C1.2, J1.4
PREVGH: D5.1 (K), EPD_C9.2, J1.21
PREVGL: D4.2 (A), EPD_C11.2, J1.23
RESE: J1.3, Q3.2 (S), R3.2
RESE': R2.2, R3.1, SJ1.2
RESET: IC1.1 (VOUT), U2.3 (EN)
RTC_RST: U2.16 (IO18), U3.4 (!RST)
RX: TP2.TP, U2.24 (RXD0/GPIO17)
SCK: D10.2, J1.13, J4.P5 (CLK), R6.1, TP8.TP, U1.6 (CLK), U2.6 (IO6)
SCL: J3.4, R2_PINH.1, SENSOR2.4 (SCK), U2.20 (IO22), U3.16 (SCL), U4.7 (SCL)
SDA: J3.3, R1_PINH.1, SENSOR2.3 (SDI), U2.19 (IO21), U3.15 (SDA), U4.8 (SDA)
SRC: C4.2, D5.2 (A), L1.1, Q3.3 (D)
SS_SD: D8.2, J4.P2 (CD/DAT3), R10.1, U2.4 (IO4)
TX: TP1.TP, U2.25 (TXD0/GPIO16)
USB_D+: D1.1 (I/O1_1), U2.14 (IO13)
USB_D-: D1.3 (I/O2_1), U2.13 (IO12)
VBAT: C2_BAT.1, MCP73831.3 (VBAT), Q1.3 (D), TP3.TP, U4.2 (CELL), U4.3 (VDD)
VBUS: C1_BAT.1, C4_USB.1, C5_USB.1, CHG_LED.A, D1.5 (VBUS), D2.2 (ANODE), MCP73831.4 (VIN), PFMF.050.1.2, Q1.1 (G), R1_PWRUSB.2, TP14.TP
VRTC: C8.1, C10_SUPERCAP.2, R_CAPACITOR.2, U3.14 (VBAT)
VUSB: J2.A4, J2.A9, J2.B4, J2.B9, PFMF.050.1.1

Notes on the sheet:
USB C connector & ESD protection
LDO Voltage Regulator
SD Card
Display Type Selector
E-Paper Drive Circuit
ESP32 C6
E-Paper Display Header
EPD Power
Environmental Sensor BME680
Voltage Supervisor + Reset & Boot / IO Button
Battery Charge Level
RTC Module DS3231SN
Test Pads
SPI ESD Protection Lines
Qwiic / Stemma QC
External NOR Flash 64MB
OpenBook Schematic
drawn by Croitoriu Cosmin
Li-Po Battery Charging Controller

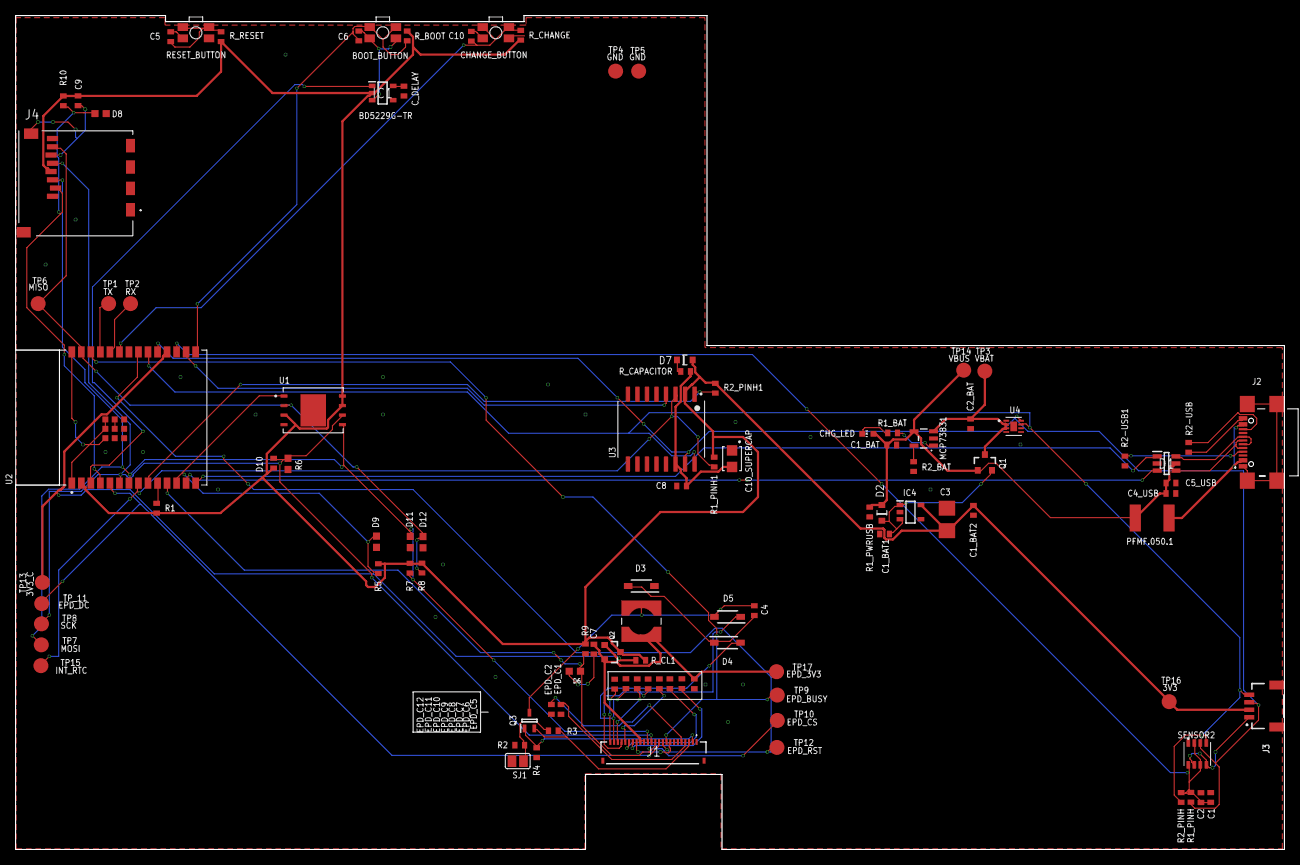
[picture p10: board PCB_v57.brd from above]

Board: 2 copper layers, 169.2 x 111.2 mm, 103 parts (0 on the bottom side), 56 nets.

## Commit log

2025-04-06 the end
    [PCB BOM.csv, PCB.brd, PnP_PCB v50_front.csv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]
2025-04-16 Added final version of the PCB file.
    [PCB_v57.brd]

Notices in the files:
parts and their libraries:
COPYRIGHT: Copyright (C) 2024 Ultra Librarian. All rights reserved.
